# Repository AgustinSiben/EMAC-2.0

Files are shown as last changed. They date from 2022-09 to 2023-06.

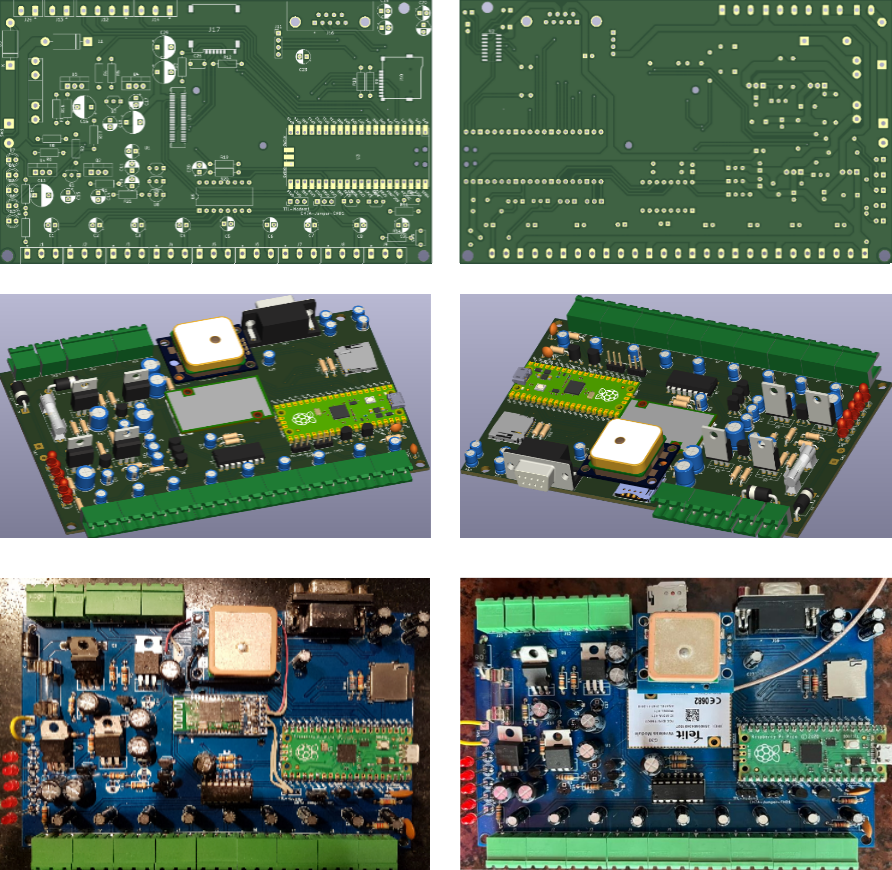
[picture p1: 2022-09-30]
Fotos/Diseño PCB.png

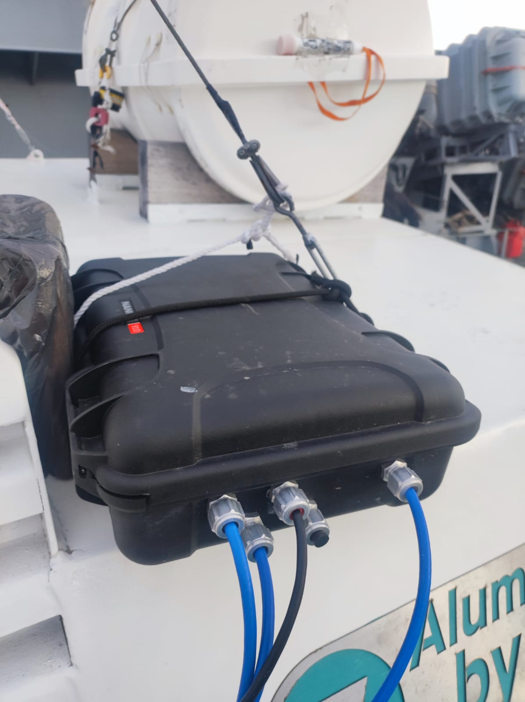
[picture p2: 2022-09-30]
Fotos/IMG-20220726-WA0014.jpg

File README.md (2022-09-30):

# EMAC-2.0
En este repositorio se encuentra contenido todo lo relacionado a la versión 2.0 del adquisidor de datos para EMAC (Estación de monitoreo ambiental costera)

Este repositorio se encuentra en desarrollo, se subiran las actualizaciones a medida que se avance en el mismo.

Ante cualquier consulta envíe un mail a la dirección: agustinsiben@gmail.com

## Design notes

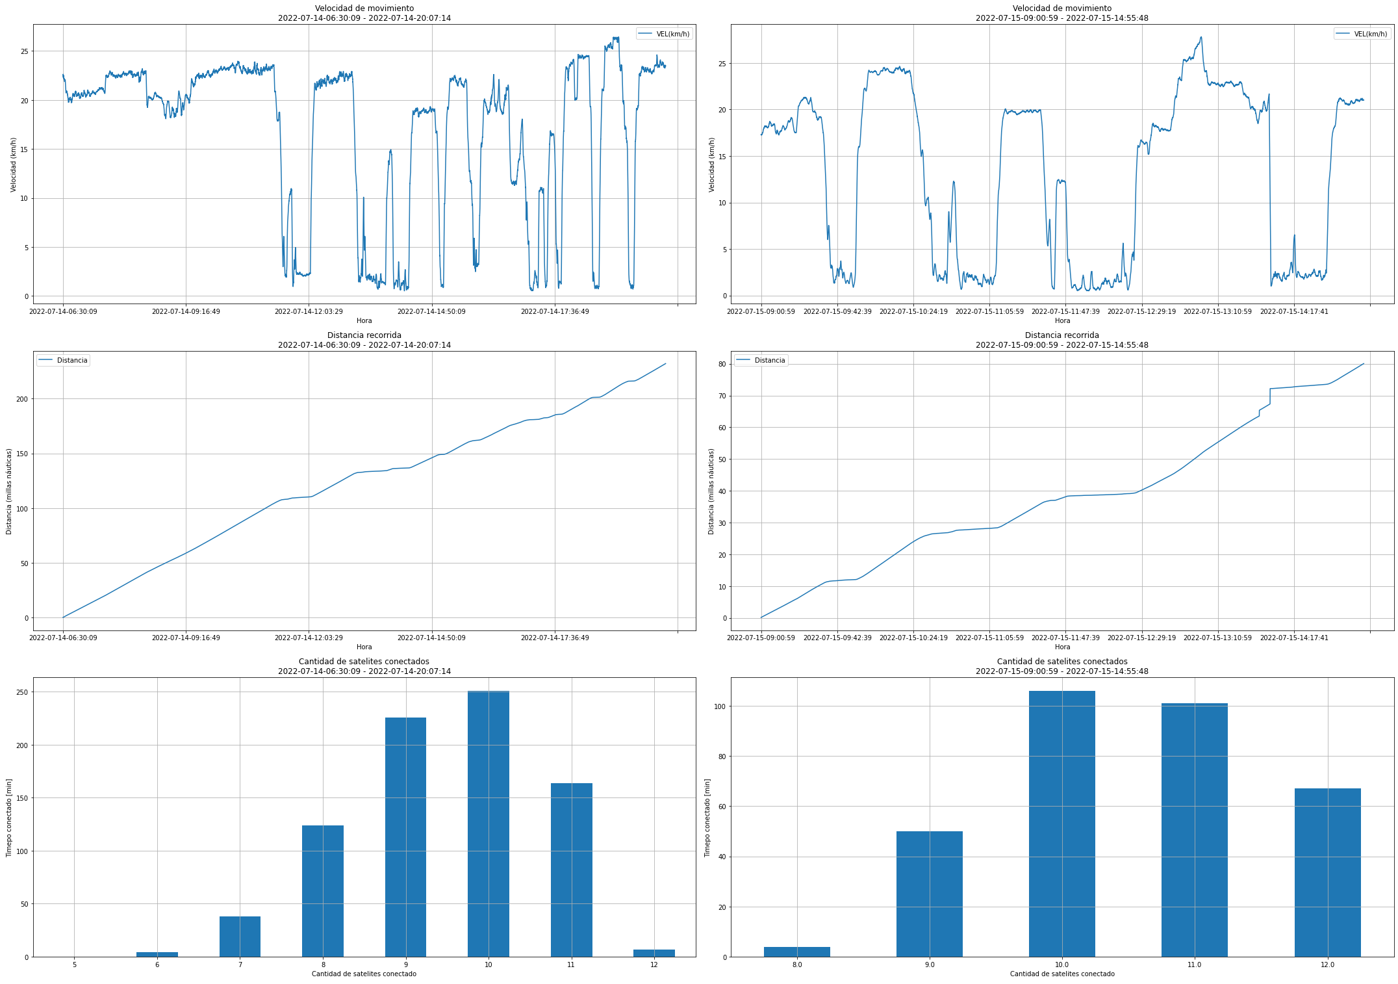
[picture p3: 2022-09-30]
Fotos/Datos_primeros_tres.png

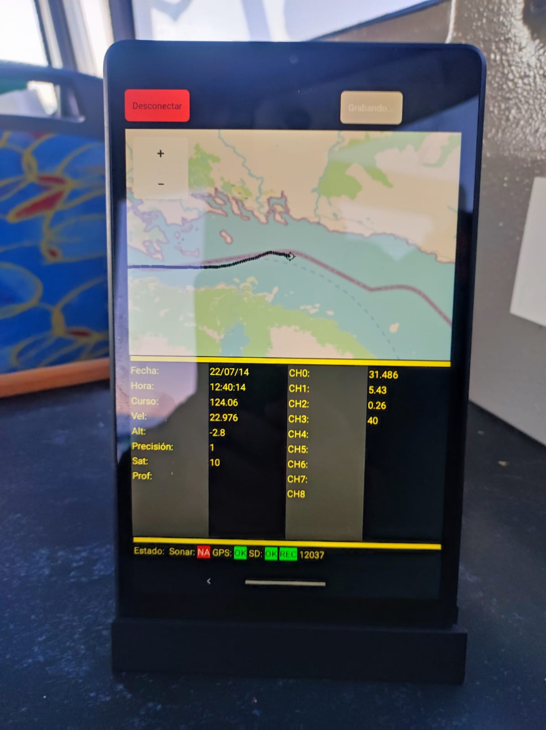
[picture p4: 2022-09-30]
Fotos/IMG-20220726-WA0013.jpg

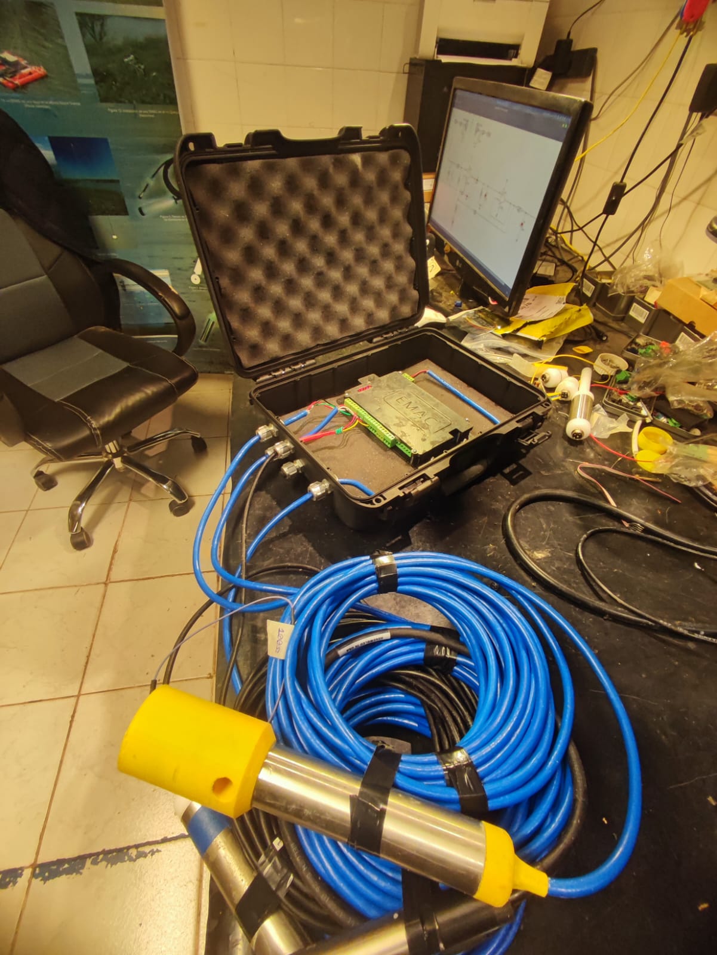
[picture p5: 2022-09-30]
Fotos/IMG-20220709-WA0045.jpg

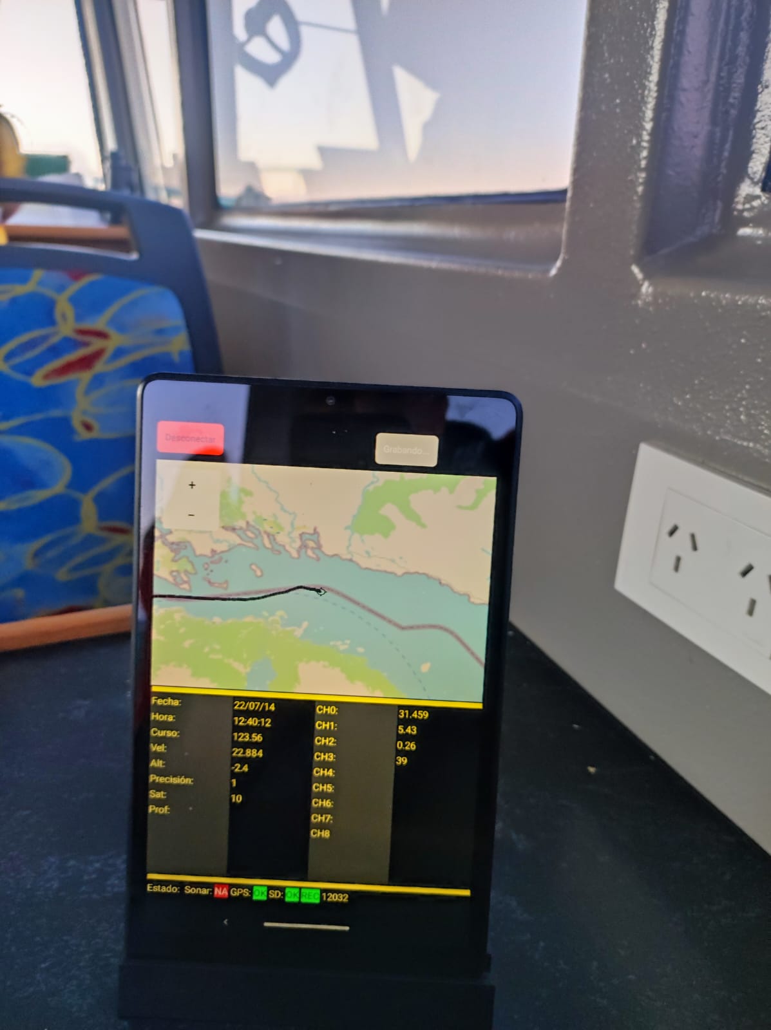
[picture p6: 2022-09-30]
Fotos/IMG-20220726-WA0007.jpg

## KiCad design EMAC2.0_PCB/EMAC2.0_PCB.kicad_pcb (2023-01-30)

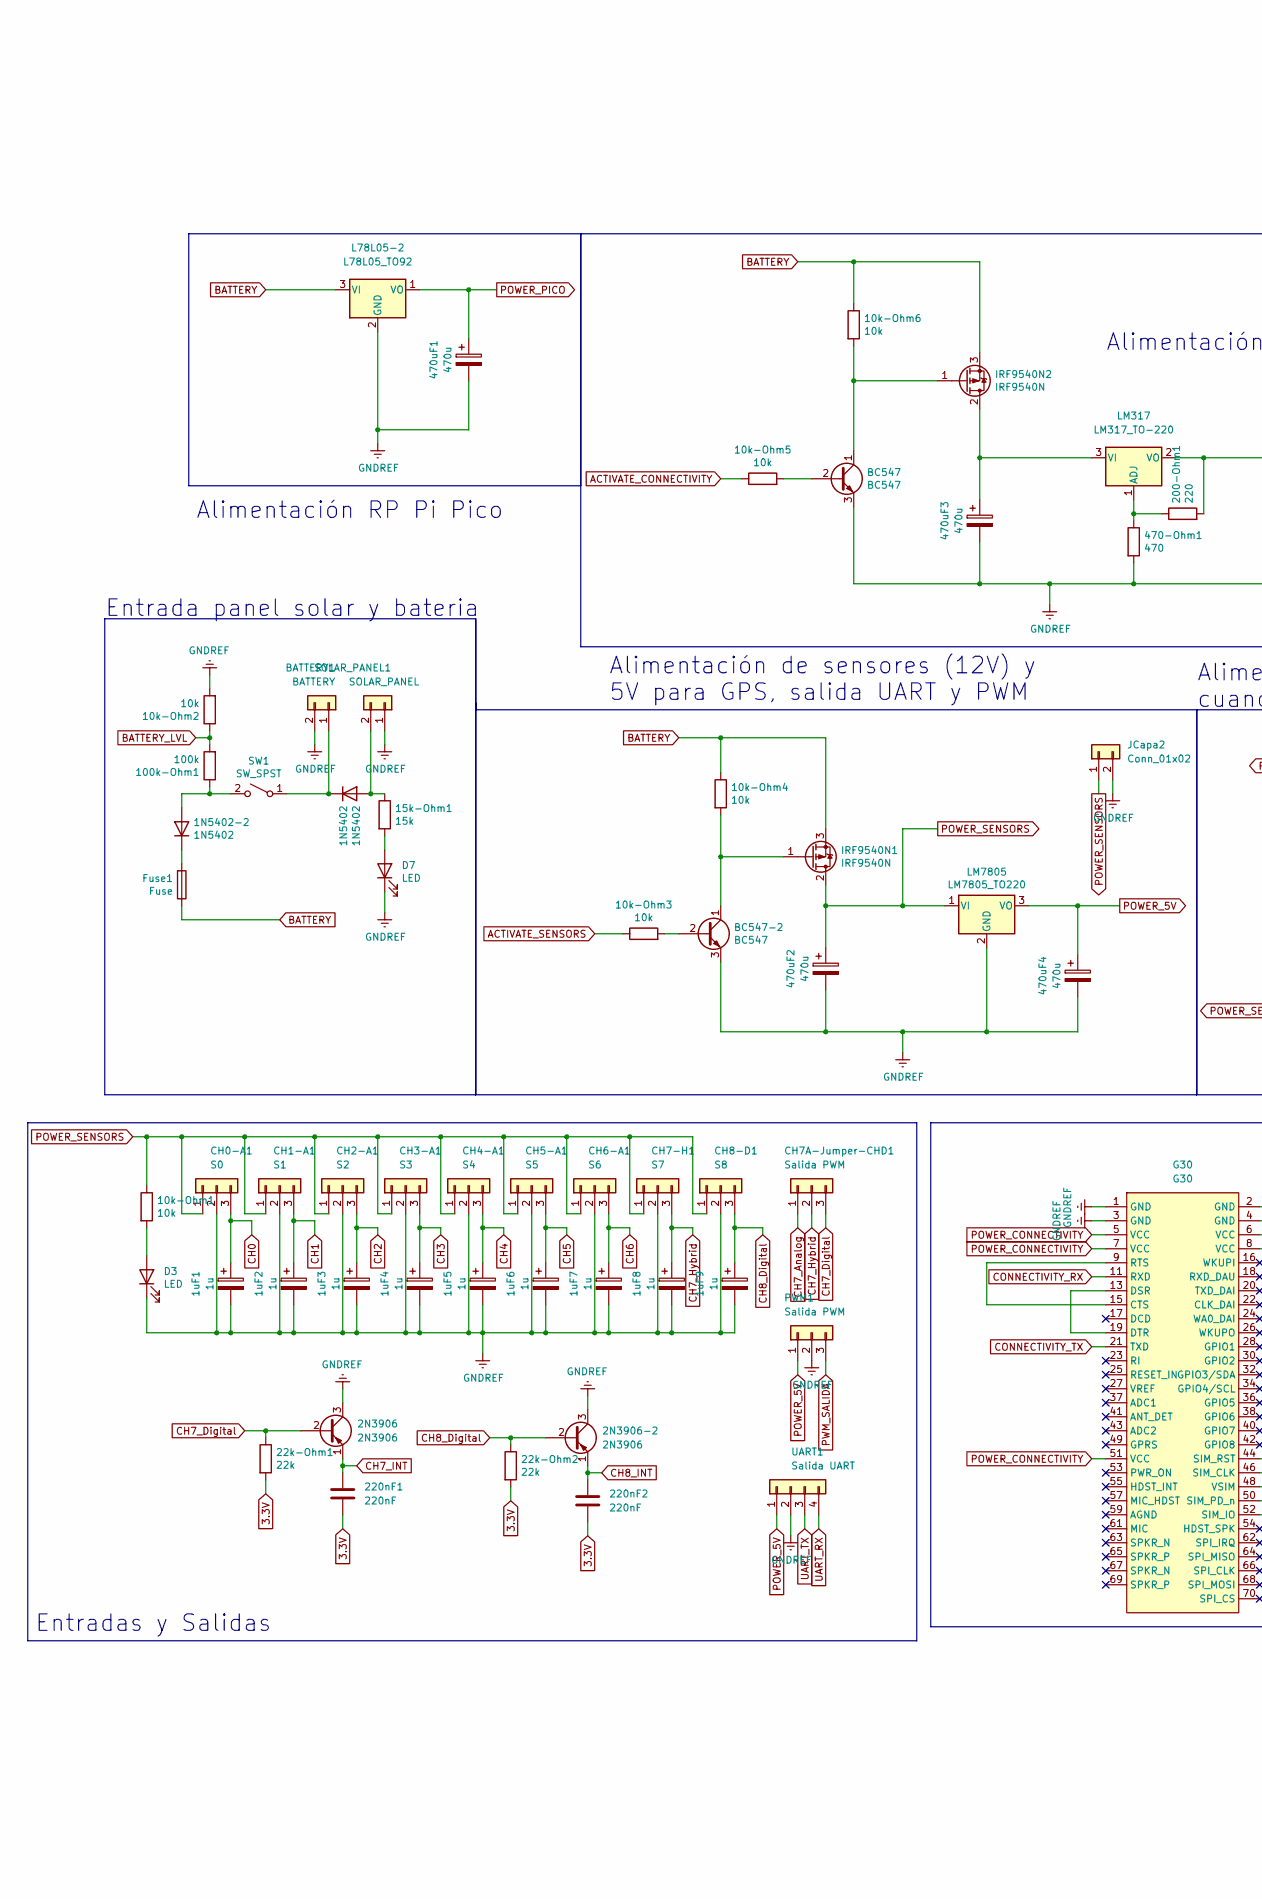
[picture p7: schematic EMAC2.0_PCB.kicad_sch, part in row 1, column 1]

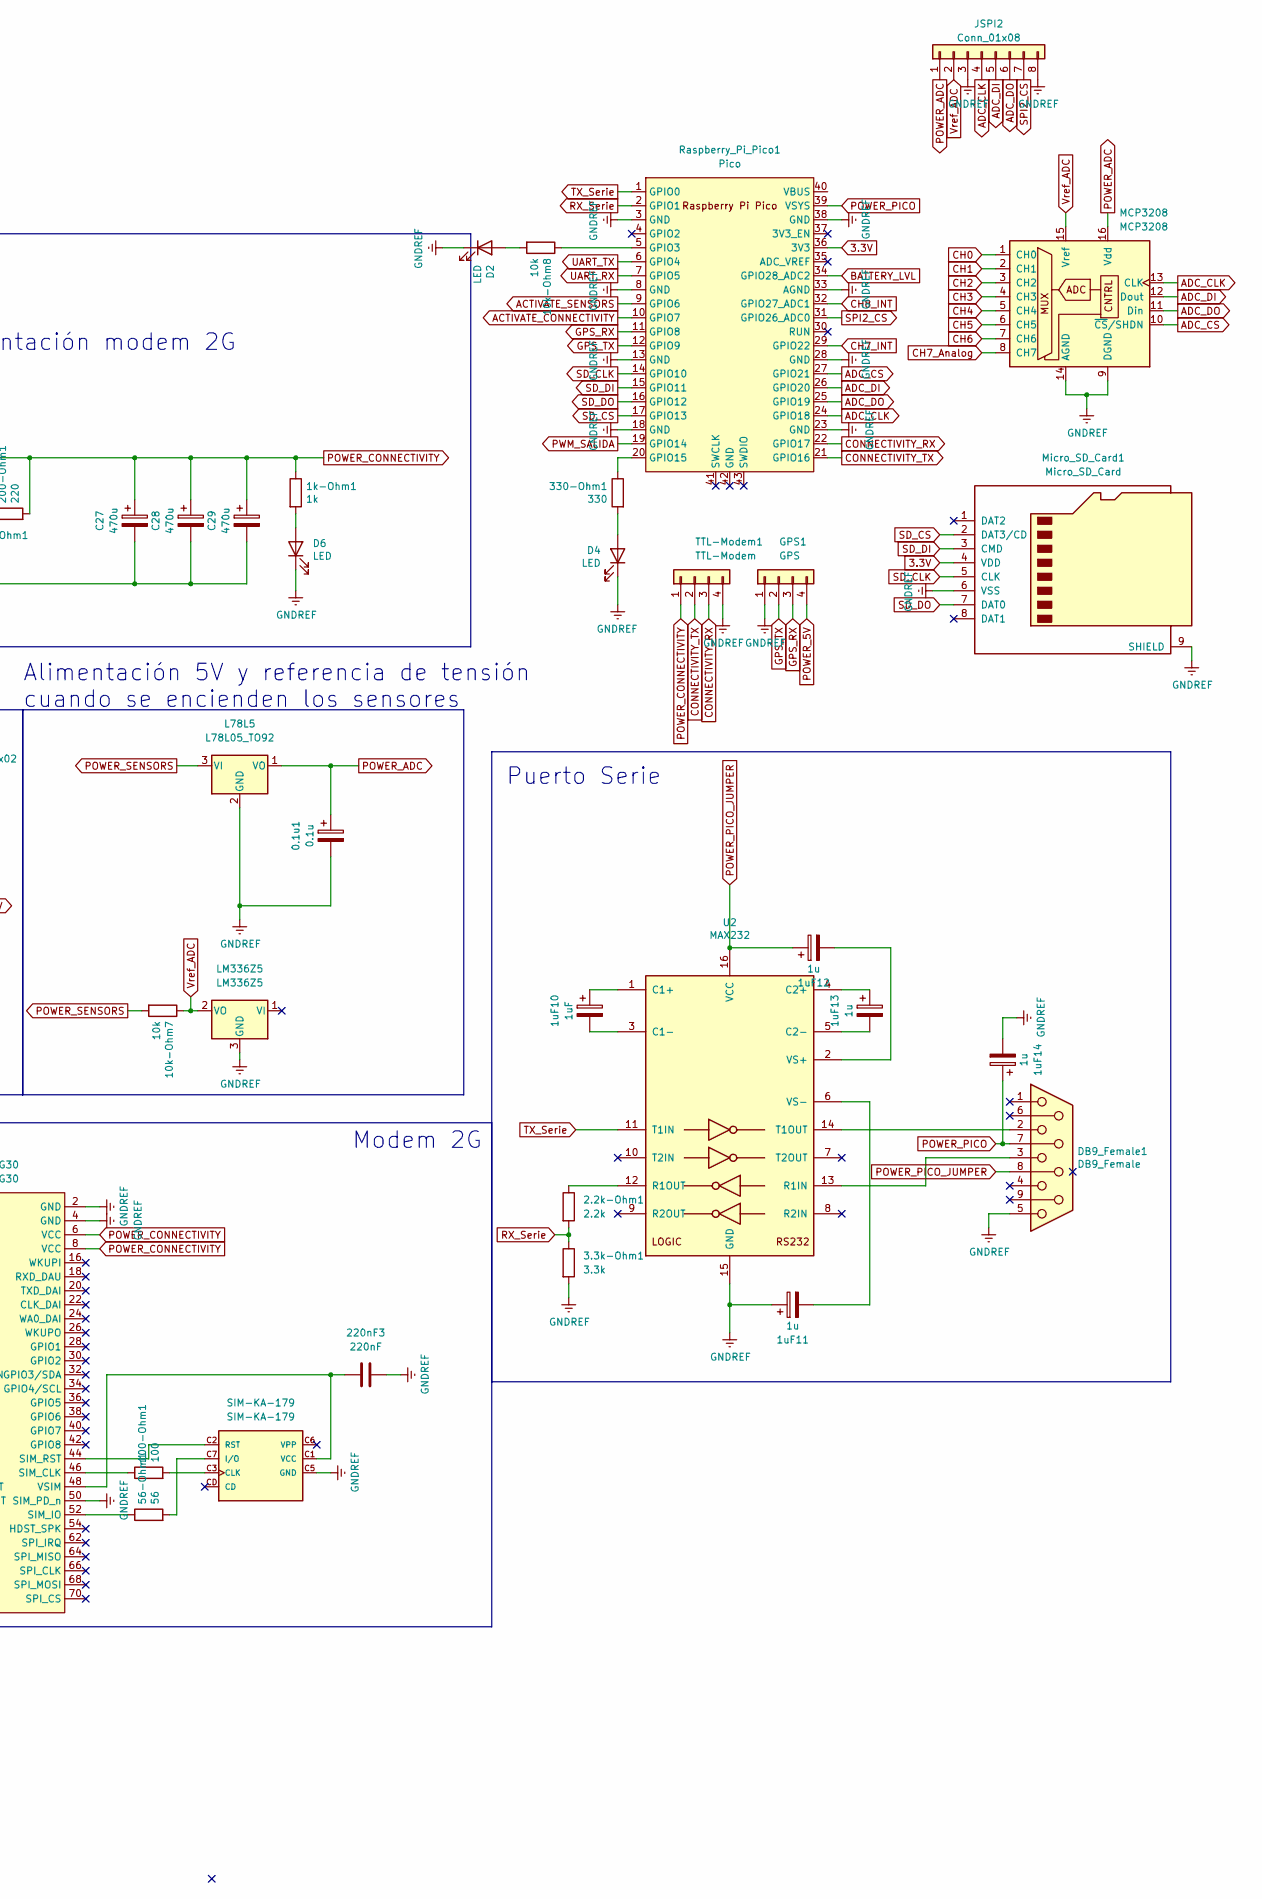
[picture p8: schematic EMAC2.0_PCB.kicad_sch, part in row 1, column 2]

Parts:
0.1u1: 0.1u; CP_Radial_D5.0mm_P2.50mm
1N5402, 1N5402-2: 1N5402; D_DO-201AD_P15.24mm_Horizontal
1k-Ohm1: 1k; R_Axial_DIN0207_L6.3mm_D2.5mm_P10.16mm_Horizontal
1uF1, 1uF2, 1uF3, 1uF4, 1uF5, 1uF6, 1uF7, 1uF8, 1uF9, 1uF11, 1uF12, 1uF13, 1uF14: 1u; CP_Radial_D5.0mm_P2.50mm
1uF10: 1uF; CP_Radial_D5.0mm_P2.50mm
2.2k-Ohm1: 2.2k; R_Axial_DIN0207_L6.3mm_D2.5mm_P10.16mm_Horizontal
2N3906, 2N3906-2: 2N3906; TO-92_Inline_Wide
3.3k-Ohm1: 3.3k; R_Axial_DIN0207_L6.3mm_D2.5mm_P10.16mm_Horizontal
10k-Ohm1, 10k-Ohm2, 10k-Ohm3, 10k-Ohm4, 10k-Ohm5, 10k-Ohm6, 10k-Ohm7, 10k-Ohm8: 10k; R_Axial_DIN0207_L6.3mm_D2.5mm_P10.16mm_Horizontal
15k-Ohm1: 15k; R_Axial_DIN0207_L6.3mm_D2.5mm_P10.16mm_Horizontal
22k-Ohm1, 22k-Ohm2: 22k; R_Axial_DIN0207_L6.3mm_D2.5mm_P10.16mm_Horizontal
56-Ohm1: 56; R_Axial_DIN0207_L6.3mm_D2.5mm_P10.16mm_Horizontal
100-Ohm1: 100; R_Axial_DIN0207_L6.3mm_D2.5mm_P10.16mm_Horizontal
100k-Ohm1: 100k; R_Axial_DIN0207_L6.3mm_D2.5mm_P10.16mm_Horizontal
200-Ohm1: 220; R_Axial_DIN0207_L6.3mm_D2.5mm_P10.16mm_Horizontal
220nF1, 220nF2, 220nF3: 220nF; C_Disc_D5.1mm_W3.2mm_P5.00mm
330-Ohm1: 330; R_Axial_DIN0207_L6.3mm_D2.5mm_P10.16mm_Horizontal
470-Ohm1: 470; R_Axial_DIN0207_L6.3mm_D2.5mm_P10.16mm_Horizontal
470uF1, 470uF2, 470uF3, 470uF4: 470u; CP_Radial_D8.0mm_P5.00mm
BATTERY1: BATTERY; PhoenixContact_MSTBA_2,5_2-G-5,08_1x02_P5.08mm_Horizontal_B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
BC547, BC547-2: BC547; TO-92_Inline_Wide
C27, C28, C29: 470u; CP_Radial_D8.0mm_P5.00mm
CH0-A1: S0; PhoenixContact_MSTBA_2,5_3-G-5,08_1x03_P5.08mm_Horizontal_B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
CH1-A1: S1; PhoenixContact_MSTBA_2,5_3-G-5,08_1x03_P5.08mm_Horizontal_B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
CH2-A1: S2; PhoenixContact_MSTBA_2,5_3-G-5,08_1x03_P5.08mm_Horizontal_B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
CH3-A1: S3; PhoenixContact_MSTBA_2,5_3-G-5,08_1x03_P5.08mm_Horizontal_B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
CH4-A1: S4; PhoenixContact_MSTBA_2,5_3-G-5,08_1x03_P5.08mm_Horizontal_B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
CH5-A1: S5; PhoenixContact_MSTBA_2,5_3-G-5,08_1x03_P5.08mm_Horizontal_B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
CH6-A1: S6; PhoenixContact_MSTBA_2,5_3-G-5,08_1x03_P5.08mm_Horizontal_B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
CH7-H1: S7; PhoenixContact_MSTBA_2,5_3-G-5,08_1x03_P5.08mm_Horizontal_B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
CH7A-Jumper-CHD1: Salida PWM; PinHeader_1x03_P2.54mm_Vertical
CH8-D1: S8; PhoenixContact_MSTBA_2,5_3-G-5,08_1x03_P5.08mm_Horizontal_B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
D2, D3, D4, D6, D7: LED; LED_D4.0mm
DB9_Female1: DB9_Female; DSUB-9_Female_Horizontal_P2.77x2.84mm_EdgePinOffset4.94mm_H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
Fuse1: Fuse; 20x5
G30: G30; Molex_SlimStack_52991-0708_2x35_P0.50mm_Vertical
GPS1: GPS; PinHeader_1x04_P2.54mm_Vertical
IRF9540N1, IRF9540N2: IRF9540N; TO-220-3_Vertical
JCapa2: Conn_01x02; PinHeader_1x02_P2.54mm_Vertical
JSPI2: Conn_01x08; PinHeader_1x08_P2.54mm_Vertical
L78L5, L78L05-2: L78L05_TO92; TO-92_Inline_Wide
LM317: LM317_TO-220; TO-220-3_Vertical
LM336Z5: LM336Z5; TO-92_Inline_Wide
LM7805: LM7805_TO220; TO-220-3_Vertical
MCP3208: MCP3208; DIP-16_W7.62mm_Socket
Micro_SD_Card1: Micro_SD_Card; GCT-MEM2055-00-190-01-A
PWM1: Salida PWM; PhoenixContact_MSTBA_2,5_3-G-5,08_1x03_P5.08mm_Horizontal_B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
Raspberry_Pi_Pico1: Pico; RPi_Pico_SMD_TH
SIM-KA-179: SIM-KA-179; GCT_SIM7100-6-1-15-00-A_REVC; PARTREV C
SOLAR_PANEL1: SOLAR_PANEL; PhoenixContact_MSTBA_2,5_2-G-5,08_1x02_P5.08mm_Horizontal_B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
SW1: SW_SPST; SolderWire-0.75sqmm_1x02_P7mm_D1.25mm_OD3.5mm
TTL-Modem1: TTL-Modem; PinHeader_1x04_P2.54mm_Vertical
U2: MAX232; SOIC-16_3.9x9.9mm_P1.27mm
UART1: Salida UART; PhoenixContact_MSTBA_2,5_4-G-5,08_1x04_P5.08mm_Horizontal_B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

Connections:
3.3V: 22k-Ohm1.2, 22k-Ohm2.2, 220nF1.2, 220nF2.2, Micro_SD_Card1.4 (VDD), Raspberry_Pi_Pico1.36 (3V3)
ACTIVATE_CONNECTIVITY: 10k-Ohm5.1, Raspberry_Pi_Pico1.10 (GPIO7)
ACTIVATE_SENSORS: 10k-Ohm3.1, Raspberry_Pi_Pico1.9 (GPIO6)
ADC_CLK: JSPI2.4, MCP3208.13 (CLK), Raspberry_Pi_Pico1.24 (GPIO18)
ADC_CS: MCP3208.10 (~CS/SHDN), Raspberry_Pi_Pico1.27 (GPIO21)
ADC_DI: JSPI2.5, MCP3208.12 (Dout), Raspberry_Pi_Pico1.26 (GPIO20)
ADC_DO: JSPI2.6, MCP3208.11 (Din), Raspberry_Pi_Pico1.25 (GPIO19)
BATTERY: 10k-Ohm4.1, 10k-Ohm6.1, Fuse1.1, IRF9540N1.3 (S), IRF9540N2.3 (S), L78L05-2.3 (VI)
BATTERY_LVL: 10k-Ohm2.1, 100k-Ohm1.2, Raspberry_Pi_Pico1.34 (GPIO28_ADC2)
CH0: 1uF1.1, CH0-A1.3, MCP3208.1 (CH0)
CH1: 1uF2.1, CH1-A1.3, MCP3208.2 (CH1)
CH2: 1uF3.1, CH2-A1.3, MCP3208.3 (CH2)
CH3: 1uF4.1, CH3-A1.3, MCP3208.4 (CH3)
CH4: 1uF5.1, CH4-A1.3, MCP3208.5 (CH4)
CH5: 1uF6.1, CH5-A1.3, MCP3208.6 (CH5)
CH6: 1uF7.1, CH6-A1.3, MCP3208.7 (CH6)
CH7_Analog: CH7A-Jumper-CHD1.1, MCP3208.8 (CH7)
CH7_Digital: 2N3906.2 (B), 22k-Ohm1.1, CH7A-Jumper-CHD1.3
CH7_Hybrid: 1uF8.1, CH7-H1.3, CH7A-Jumper-CHD1.2
CH7_INT: 2N3906.1 (E), 220nF1.1, Raspberry_Pi_Pico1.29 (GPIO22)
CH8_Digital: 1uF9.1, 2N3906-2.2 (B), 22k-Ohm2.1, CH8-D1.3
CH8_INT: 2N3906-2.1 (E), 220nF2.1, Raspberry_Pi_Pico1.32 (GPIO27_ADC1)
CONNECTIVITY_RX: G30.11 (RXD), Raspberry_Pi_Pico1.22 (GPIO17), TTL-Modem1.3
CONNECTIVITY_TX: G30.21 (TXD), Raspberry_Pi_Pico1.21 (GPIO16), TTL-Modem1.2
GNDREF: 0.1u1.2, 1uF1.2, 1uF2.2, 1uF3.2, 1uF4.2, 1uF5.2, 1uF6.2, 1uF7.2, 1uF8.2, 1uF9.2, 1uF11.1, 1uF14.2, 2N3906.3 (C), 2N3906-2.3 (C), 3.3k-Ohm1.2, 10k-Ohm2.2, 220nF3.1, 470-Ohm1.2, 470uF1.2, 470uF2.2, 470uF3.2, 470uF4.2, BATTERY1.2, BC547.3 (E), BC547-2.3 (E), C27.2, C28.2, C29.2, CH0-A1.2, CH1-A1.2, CH2-A1.2, CH3-A1.2, CH4-A1.2, CH5-A1.2, CH6-A1.2, CH7-H1.2, CH8-D1.2, D2.1 (K), D3.1 (K), D4.1 (K), D6.1 (K), D7.1 (K), DB9_Female1.5, G30.1 (GND), G30.2 (GND), G30.3 (GND), G30.4 (GND), G30.50 (SIM_PD_n), GPS1.1, JCapa2.2, JSPI2.3, JSPI2.8, L78L5.2 (GND), L78L05-2.2 (GND), LM336Z5.3 (GND), LM7805.2 (GND), MCP3208.9 (DGND), MCP3208.14 (AGND), Micro_SD_Card1.6 (VSS), Micro_SD_Card1.9 (SHIELD), PWM1.2, Raspberry_Pi_Pico1.3 (GND), Raspberry_Pi_Pico1.8 (GND), Raspberry_Pi_Pico1.13 (GND), Raspberry_Pi_Pico1.18 (GND), Raspberry_Pi_Pico1.23 (GND), Raspberry_Pi_Pico1.28 (GND), Raspberry_Pi_Pico1.33 (AGND), Raspberry_Pi_Pico1.38 (GND), SIM-KA-179.C5 (GND), SOLAR_PANEL1.1, TTL-Modem1.4, U2.15 (GND), UART1.2
GPS_RX: GPS1.3, Raspberry_Pi_Pico1.11 (GPIO8)
GPS_TX: GPS1.2, Raspberry_Pi_Pico1.12 (GPIO9)
unnamed: 1N5402-2.1 (K), Fuse1.2
unnamed: 1N5402.1 (K), BATTERY1.1, SW1.1 (A)
unnamed: 1k-Ohm1.2, D6.2 (A)
unnamed: 1uF10.1, U2.1 (C1+)
unnamed: 1uF10.2, U2.3 (C1-)
unnamed: 1uF11.2, U2.6 (VS-)
unnamed: 1uF12.2, U2.2 (VS+)
unnamed: 1uF13.1, U2.4 (C2+)
unnamed: 1uF13.2, U2.5 (C2-)
unnamed: 2.2k-Ohm1.1, U2.12 (R1OUT)
unnamed: 10k-Ohm1.2, D3.2 (A)
unnamed: 10k-Ohm3.2, BC547-2.2 (B)
unnamed: 10k-Ohm4.2, BC547-2.1 (C), IRF9540N1.1 (G)
unnamed: 10k-Ohm5.2, BC547.2 (B)
unnamed: 10k-Ohm6.2, BC547.1 (C), IRF9540N2.1 (G)
unnamed: 10k-Ohm8.1, Raspberry_Pi_Pico1.5 (GPIO3)
unnamed: 10k-Ohm8.2, D2.2 (A)
unnamed: 1N5402.2 (A), 15k-Ohm1.1, SOLAR_PANEL1.2
unnamed: 15k-Ohm1.2, D7.2 (A)
unnamed: 56-Ohm1.1, G30.52 (SIM_IO)
unnamed: 56-Ohm1.2, SIM-KA-179.C7 (I/O)
unnamed: 100-Ohm1.1, G30.46 (SIM_CLK)
unnamed: 100-Ohm1.2, SIM-KA-179.C3 (CLK)
unnamed: 1N5402-2.2 (A), 100k-Ohm1.1, SW1.2 (B)
unnamed: 200-Ohm1.1, 470-Ohm1.1, LM317.1 (ADJ)
unnamed: 220nF3.2, G30.48 (VSIM), SIM-KA-179.C1 (VCC)
unnamed: 330-Ohm1.1, Raspberry_Pi_Pico1.20 (GPIO15)
unnamed: 330-Ohm1.2, D4.2 (A)
unnamed: 470uF3.1, IRF9540N2.2 (D), LM317.3 (VI)
unnamed: DB9_Female1.2, U2.14 (T1OUT)
unnamed: DB9_Female1.3, U2.13 (R1IN)
unnamed: G30.13 (DSR), G30.19 (DTR)
unnamed: G30.9 (RTS), G30.15 (CTS)
unnamed: G30.44 (SIM_RST), SIM-KA-179.C2 (RST)
POWER_5V: 470uF4.1, GPS1.4, LM7805.3 (VO), PWM1.1, UART1.1
POWER_ADC: 0.1u1.1, JSPI2.1, L78L5.1 (VO), MCP3208.16 (Vdd)
POWER_CONNECTIVITY: 1k-Ohm1.1, 200-Ohm1.2, C27.1, C28.1, C29.1, G30.5 (VCC), G30.6 (VCC), G30.7 (VCC), G30.8 (VCC), G30.51 (VCC), LM317.2 (VO), TTL-Modem1.1
POWER_PICO: 1uF14.1, 470uF1.1, DB9_Female1.7, L78L05-2.1 (VO), Raspberry_Pi_Pico1.39 (VSYS)
POWER_PICO_JUMPER: 1uF12.1, DB9_Female1.8, U2.16 (VCC)
POWER_SENSORS: 10k-Ohm1.1, 10k-Ohm7.2, 470uF2.1, CH0-A1.1, CH1-A1.1, CH2-A1.1, CH3-A1.1, CH4-A1.1, CH5-A1.1, CH6-A1.1, CH7-H1.1, CH8-D1.1, IRF9540N1.2 (D), JCapa2.1, L78L5.3 (VI), LM7805.1 (VI)
PWM_SALIDA: PWM1.3, Raspberry_Pi_Pico1.19 (GPIO14)
RX_Serie: 2.2k-Ohm1.2, 3.3k-Ohm1.1, Raspberry_Pi_Pico1.2 (GPIO1)
SD_CLK: Micro_SD_Card1.5 (CLK), Raspberry_Pi_Pico1.14 (GPIO10)
SD_CS: Micro_SD_Card1.2 (DAT3/CD), Raspberry_Pi_Pico1.17 (GPIO13)
SD_DI: Micro_SD_Card1.3 (CMD), Raspberry_Pi_Pico1.15 (GPIO11)
SD_DO: Micro_SD_Card1.7 (DAT0), Raspberry_Pi_Pico1.16 (GPIO12)
SPI2_CS: JSPI2.7, Raspberry_Pi_Pico1.31 (GPIO26_ADC0)
TX_Serie: Raspberry_Pi_Pico1.1 (GPIO0), U2.11 (T1IN)
UART_RX: Raspberry_Pi_Pico1.7 (GPIO5), UART1.4
UART_TX: Raspberry_Pi_Pico1.6 (GPIO4), UART1.3
Vref_ADC: 10k-Ohm7.1, JSPI2.2, LM336Z5.2 (VO), MCP3208.15 (Vref)

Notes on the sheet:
Modem 2G
Alimentación modem 2G
Alimentación 5V y referencia de tensión cuando se encienden los sensores
Entradas y Salidas
Entrada panel solar y bateria
Alimentación RP Pi Pico
Puerto Serie
Alimentación de sensores (12V) y 5V para GPS, salida UART y PWM

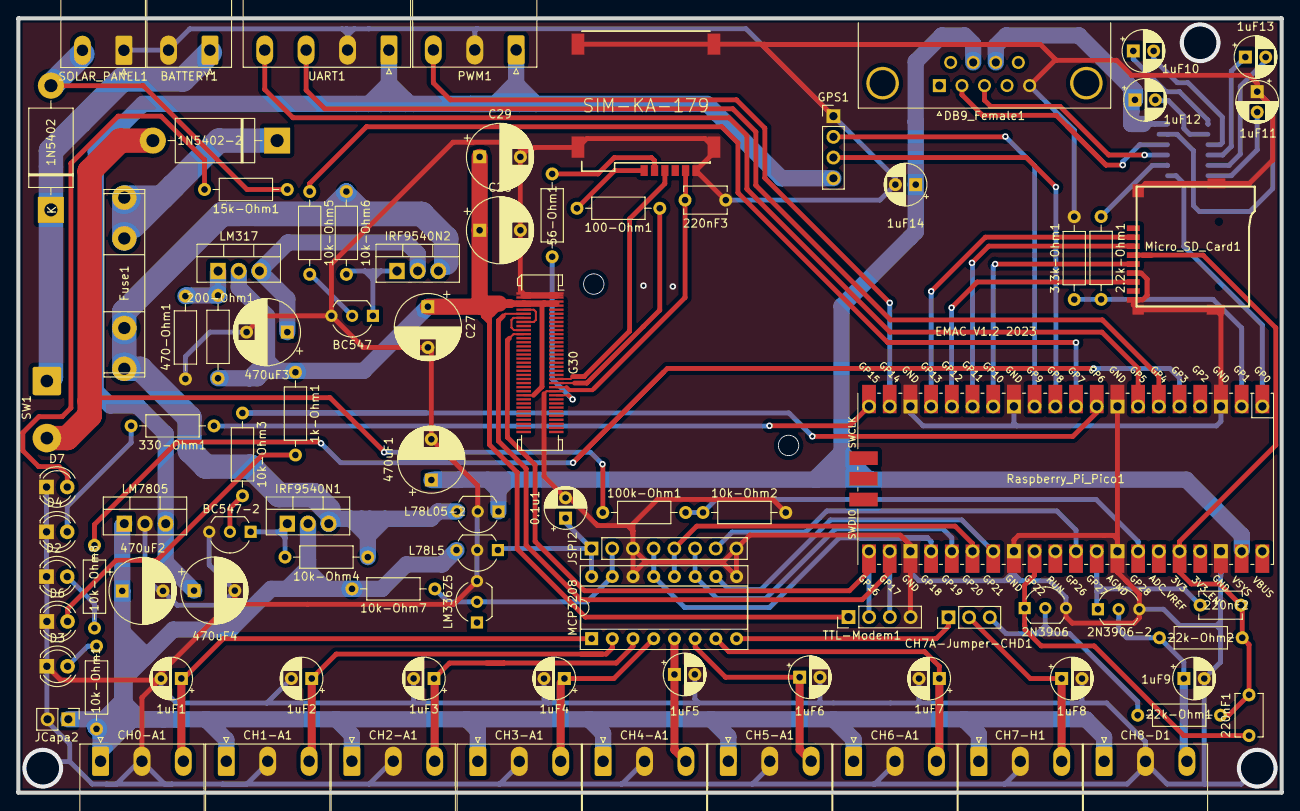
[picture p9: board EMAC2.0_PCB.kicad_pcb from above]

Board: 2 copper layers, 155.0 x 95.0 mm, 90 parts (1 on the bottom side), 78 nets.

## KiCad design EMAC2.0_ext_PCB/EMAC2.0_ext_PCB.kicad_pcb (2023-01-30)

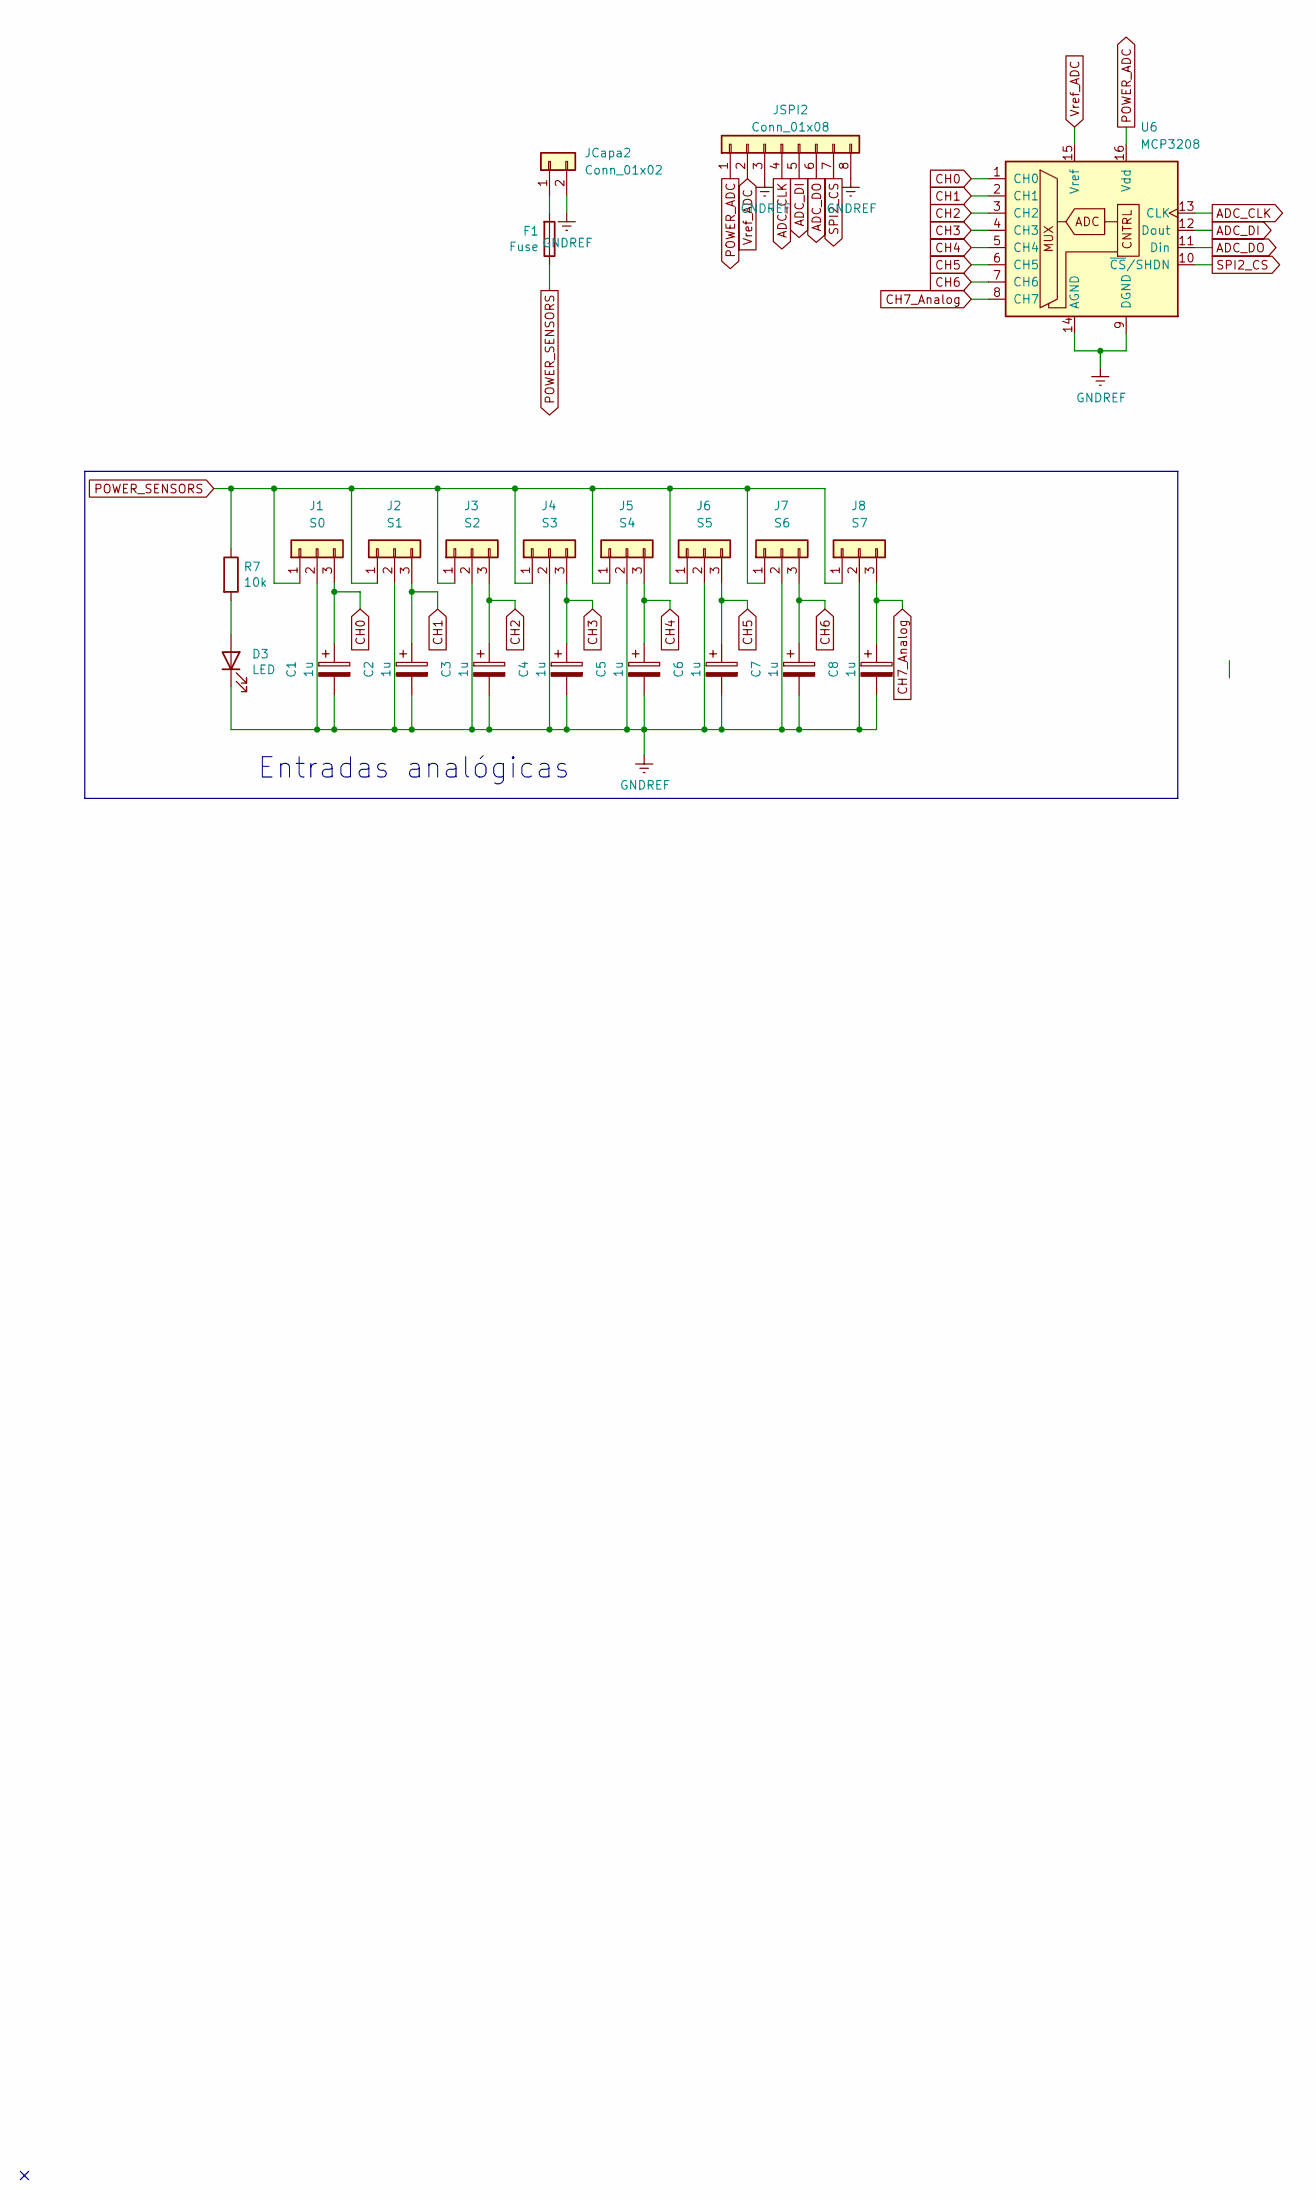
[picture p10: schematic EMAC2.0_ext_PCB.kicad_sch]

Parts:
C1, C2, C3, C4, C5, C6, C7, C8: 1u; CP_Radial_D5.0mm_P2.50mm
D3: LED; LED_D4.0mm
F1: Fuse; 20x5
J1: S0; PhoenixContact_MSTBA_2,5_3-G-5,08_1x03_P5.08mm_Horizontal_B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
J2: S1; PhoenixContact_MSTBA_2,5_3-G-5,08_1x03_P5.08mm_Horizontal_B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
J3: S2; PhoenixContact_MSTBA_2,5_3-G-5,08_1x03_P5.08mm_Horizontal_B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
J4: S3; PhoenixContact_MSTBA_2,5_3-G-5,08_1x03_P5.08mm_Horizontal_B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
J5: S4; PhoenixContact_MSTBA_2,5_3-G-5,08_1x03_P5.08mm_Horizontal_B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
J6: S5; PhoenixContact_MSTBA_2,5_3-G-5,08_1x03_P5.08mm_Horizontal_B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
J7: S6; PhoenixContact_MSTBA_2,5_3-G-5,08_1x03_P5.08mm_Horizontal_B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
J8: S7; PhoenixContact_MSTBA_2,5_3-G-5,08_1x03_P5.08mm_Horizontal_B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
JCapa2: Conn_01x02; PinHeader_1x02_P2.54mm_Vertical
JSPI2: Conn_01x08; PinHeader_1x08_P2.54mm_Vertical
R7: 10k; R_Axial_DIN0207_L6.3mm_D2.5mm_P10.16mm_Horizontal
U6: MCP3208; DIP-16_W7.62mm_Socket

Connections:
ADC_CLK: JSPI2.4, U6.13 (CLK)
ADC_DI: JSPI2.5, U6.12 (Dout)
ADC_DO: JSPI2.6, U6.11 (Din)
CH0: C1.1, J1.3, U6.1 (CH0)
CH1: C2.1, J2.3, U6.2 (CH1)
CH2: C3.1, J3.3, U6.3 (CH2)
CH3: C4.1, J4.3, U6.4 (CH3)
CH4: C5.1, J5.3, U6.5 (CH4)
CH5: C6.1, J6.3, U6.6 (CH5)
CH6: C7.1, J7.3, U6.7 (CH6)
CH7_Analog: C8.1, J8.3, U6.8 (CH7)
GNDREF: C1.2, C2.2, C3.2, C4.2, C5.2, C6.2, C7.2, C8.2, D3.1 (K), J1.2, J2.2, J3.2, J4.2, J5.2, J6.2, J7.2, J8.2, JCapa2.2, JSPI2.3, JSPI2.8, U6.9 (DGND), U6.14 (AGND)
unnamed: D3.2 (A), R7.2
unnamed: F1.2, JCapa2.1
POWER_ADC: JSPI2.1, U6.16 (Vdd)
POWER_SENSORS: F1.1, J1.1, J2.1, J3.1, J4.1, J5.1, J6.1, J7.1, J8.1, R7.1
SPI2_CS: JSPI2.7, U6.10 (~CS/SHDN)
Vref_ADC: JSPI2.2, U6.15 (Vref)

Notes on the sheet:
Entradas analógicas

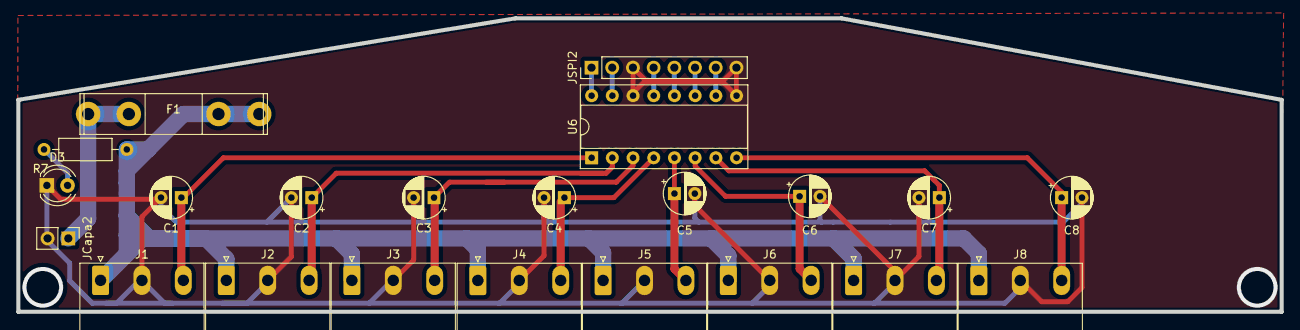
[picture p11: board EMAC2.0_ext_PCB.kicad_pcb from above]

Board: 2 copper layers, 155.0 x 36.0 mm, 22 parts (0 on the bottom side), 18 nets.

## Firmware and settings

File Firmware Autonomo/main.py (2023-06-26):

# import gc # type: ignore
from ujson import load  # type: ignore
from micropython import mem_info  # type: ignore
from machine import Pin, Timer  # type: ignore
import uasyncio as asynci
from lib.comunication import *
from lib.emac import data_logger

Pin(3, Pin.OUT, value=1)  # type: ignore
# Start Pins to GND
for i in [0, 1, 2, 4, 5, 6, 7, 8, 9, 10, 11, 12, 13, 14, 15, 16, 17, 18, 19, 20, 21, 22, 26, 27, 28]:
    Pin(i, Pin.IN)  # type: ignore

# Timers
state_timer = Timer()
restart_digital_timer = Timer()
MAIN_PERIOD = 100
DIGITAL_RESTART_FREQ = 0.1


def next_state(self) -> None:
    data_logger.next_state()


def ch7_counter(self) -> None:
    data_logger._channels.ch7_add()


def ch8_counter(self) -> None:
    data_logger._channels.ch8_add()


def digital_update(self) -> None:
    data_logger._channels.digital_update()


async def main() -> None:
    # Digital interrups
    # Ch7 Interrupt - Not implemented on Mercury
    # Pin(22, Pin.IN, Pin.PULL_UP).irq(trigger=Pin.IRQ_RISING,
    #                                 handler=ch7_counter)
    # Ch8 Interrupt
    Pin(27, Pin.IN, Pin.PULL_UP).irq(trigger=Pin.IRQ_RISING,
                                     handler=ch8_counter)
    # Digital
    state_timer.init(mode=Timer.PERIODIC,
                     period=MAIN_PERIOD,
                     callback=next_state)

    restart_digital_timer.init(freq=DIGITAL_RESTART_FREQ,
                               mode=Timer.PERIODIC,
                               callback=digital_update)

    # Asyncio tasks
    await asyncio.gather(asyncio.create_task(request_configuration(60)),
                         asyncio.create_task(check_communications(100)),
                         asyncio.create_task(connect_socket()),
                         asyncio.create_task(modem_check()))


if __name__ == '__main__':
    asyncio.run(main())

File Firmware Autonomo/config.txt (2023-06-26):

config 6235072c8835072c780026000101010101010101010058585858
wireless_config ate0, AT+CREG=1, AT+MIPCALL=1,"igprs.claro.com.ar","","", AT+MIPOPEN=1,40000,"190.124.196.178",40000,0
communication_using WIFI
ssid_password 29300000000008WF admin123
ip_port 190.124.196.178 8080
periodes_to_send 2
mercurry_v_ref 5.02
emac_vref 4.894

ssid_password BVNET-4CB24CB2 H7KFYX77TYMRNV44

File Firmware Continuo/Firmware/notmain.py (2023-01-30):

from micropython import const, mem_info # type: ignore
from machine import Pin, Timer # type: ignore
from emac import emac20 # type: ignore
from time import ticks_ms, ticks_diff

#Constants
MAIN_PERIOD = const(100)
DIGITAL_RESTART_FREQ = const(0.1)

#Corrige un ERROR de PCB resuelto para proximas versiones
Pin(3, Pin.OUT, value = 1) # type: ignore
# Start Pins to GND
for i in [0,1,2,4,5,6,7,8,9,10,11,12,13,14,15,16,17,18,19,20,21,22,26,27,28,"LED"]:
    Pin(i, Pin.OUT, value = 0) # type: ignore

#Digital inputs
ch7_digital = Pin(22,Pin.IN, Pin.PULL_UP)
ch8_digital = Pin(27,Pin.IN, Pin.PULL_UP)

#Data logger
data_logger = emac20()

#Timers
state_timer = Timer()
restart_digital_timer = Timer()

def main()->None:
    #Digital interrups
    ch7_digital.irq(trigger = Pin.IRQ_FALLING, handler=ch7_counter)
    ch8_digital.irq(trigger = Pin.IRQ_FALLING, handler=ch8_counter)
    #Digital
    restart_digital_timer.init(freq=DIGITAL_RESTART_FREQ, mode=Timer.PERIODIC, callback=digital_update)
    state_timer.init(mode= Timer.PERIODIC, period= MAIN_PERIOD, callback= sample)
    

def sample(self)-> None:
    #print(gc.mem_free()/1024) #RAM in Kbytes
    data_logger.sample()
    return

def ch7_counter(self)->None:
    data_logger._channels.ch7_add()
    return

def ch8_counter(self)->None:
    data_logger._channels.ch8_add()
    return

def digital_update(self)->None:
    data_logger._channels.digital_update()
    return

if __name__ == '__main__':
    main()
